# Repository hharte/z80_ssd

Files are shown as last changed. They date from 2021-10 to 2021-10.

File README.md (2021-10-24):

# z80_ssd: Z-80 Solid-State Drive

## Introduction

This project implements a solid-state disk controller for the Z80.  The board plugs into the Z80 CPU socket and the Z80 CPU plugs into the board.  A [Microchip PIC18F47Q43](https://www.microchip.com/en-us/product/PIC18F47Q43) microcontroller implements the controller and SD Memory card interface using SPI.

While the z80_ssd could implement almost any hard disk controller that uses I/O ports for data transfer, the particular controller implemented mimics the IBC/Integrated Business Computers MCC Hard Disk Controller.

The original controller supports four ST-506 drives.  Drive 0 is the boot drive, and Drive 3 is a 5- or 10MB removable cartridge drive.  The other two drives were unused in the standard [IBC MultiStar](https://github.com/hharte/integrated-business-computers/tree/master/MultiStar) computer.

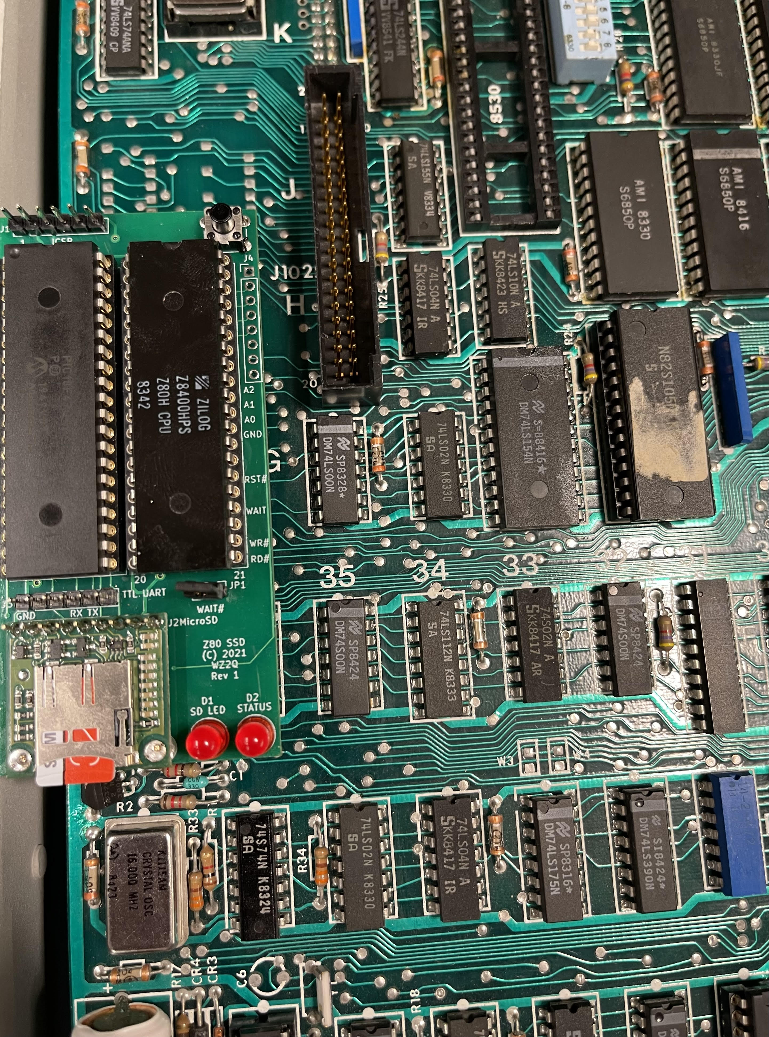
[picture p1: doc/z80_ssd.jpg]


## Architecture

### I/O Access Handling

The z80_ssd piggybacks on the Z80 CPU socket to gain access to all of the Z80 CPU’s signals.  The PIC18F47Q43 was chosen because it has a relatively large amount of RAM (8K) and FLASH (128K.)  To minimize the number of components required, and to facilitate maximum flexibility, the MCU’s Configurable Logic Cells (CLCs) are used:

CLC1 - Decodes CPU_A[7:4] to allow the z80_ssd to respond to a block of 16 I/O addresses.  The current design uses one 4-input AND gate to decode address 40h-4Fh, like the original disk controller.  There are three spare 4-input AND gates in CLC1, so the design could be expanded to decode up to four blocks of 16 I/O ports if desired.

This schematic diagram illustrates three address ranges decoded by the z80_ssd: 40h-4Fh, 0C0h-0CFh, 0D0h-0DFh.

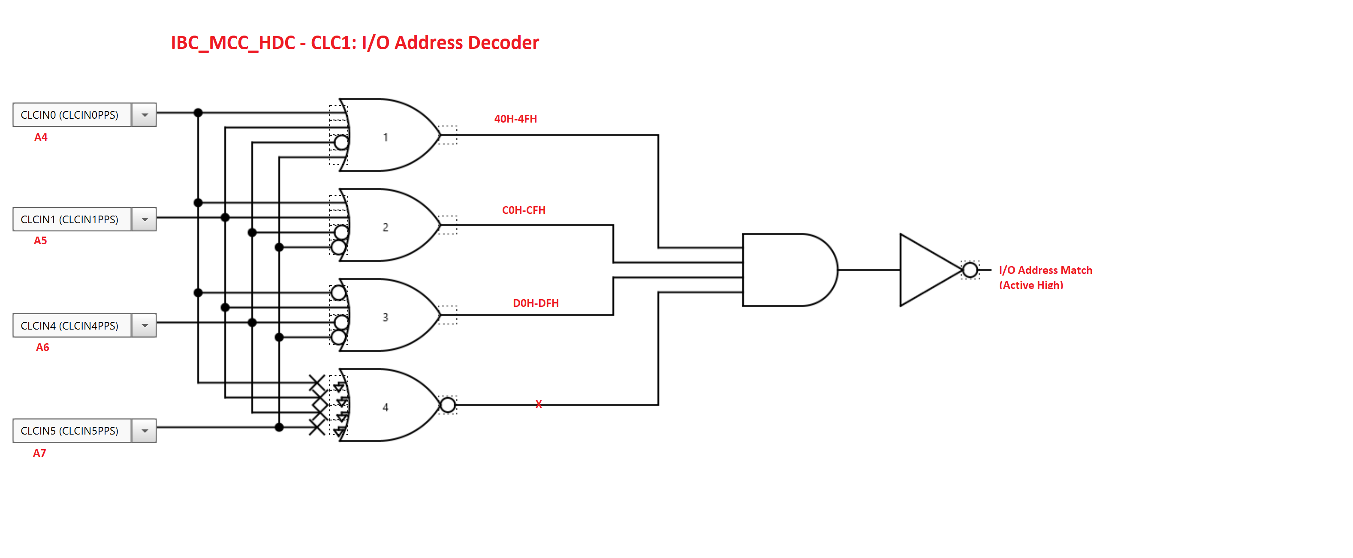
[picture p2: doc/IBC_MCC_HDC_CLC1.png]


CLC2 - Uses the output of CLC1 along with CPU_M1# and CPU_IORQ# to set a flip-flop when the requested I/O access is performed by the CPU.  The output of this flip-flop pulls down the CPU_WAIT# pin via an open-collector output from the MCU.  CLC2 generates an interrupt to the MCU, and MCU then processes the I/O read or write.  After the MCU finishes processing the I/O access, it de-asserts WAIT# by resetting the flip-flop in CLC2.

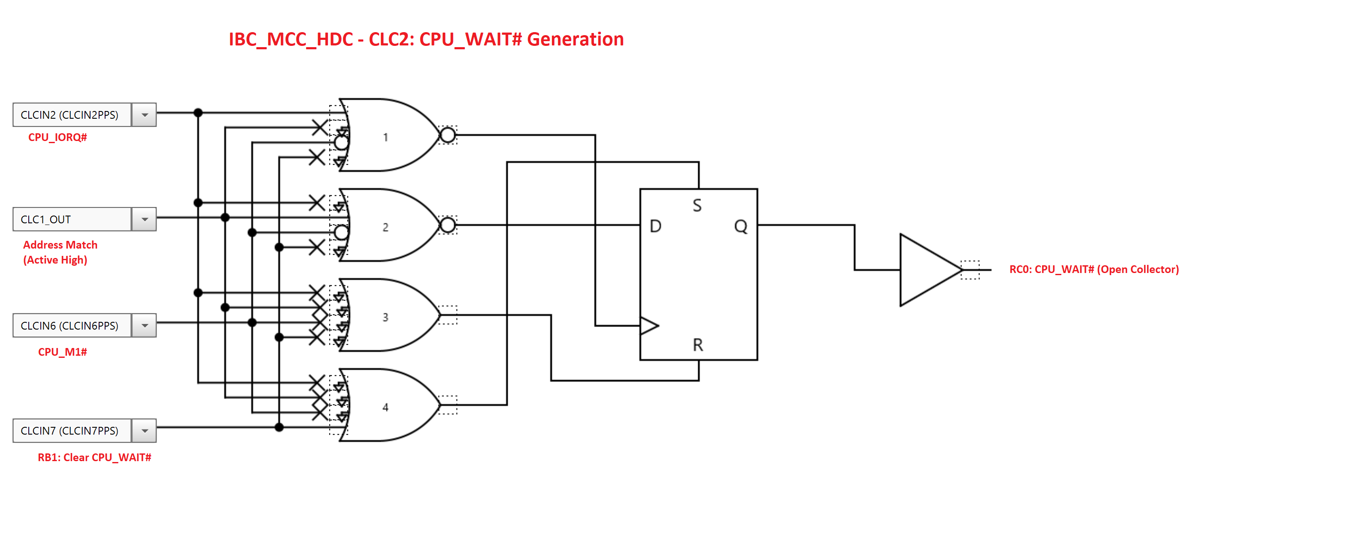
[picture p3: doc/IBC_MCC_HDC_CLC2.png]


CLC3 - Although not strictly required, the z80_ssd employs a 74ABTH245 bus transceiver for the CPU data bus to ensure proper timing.  The MCU’s CLC3 drives the bus transceiver’s output enable.

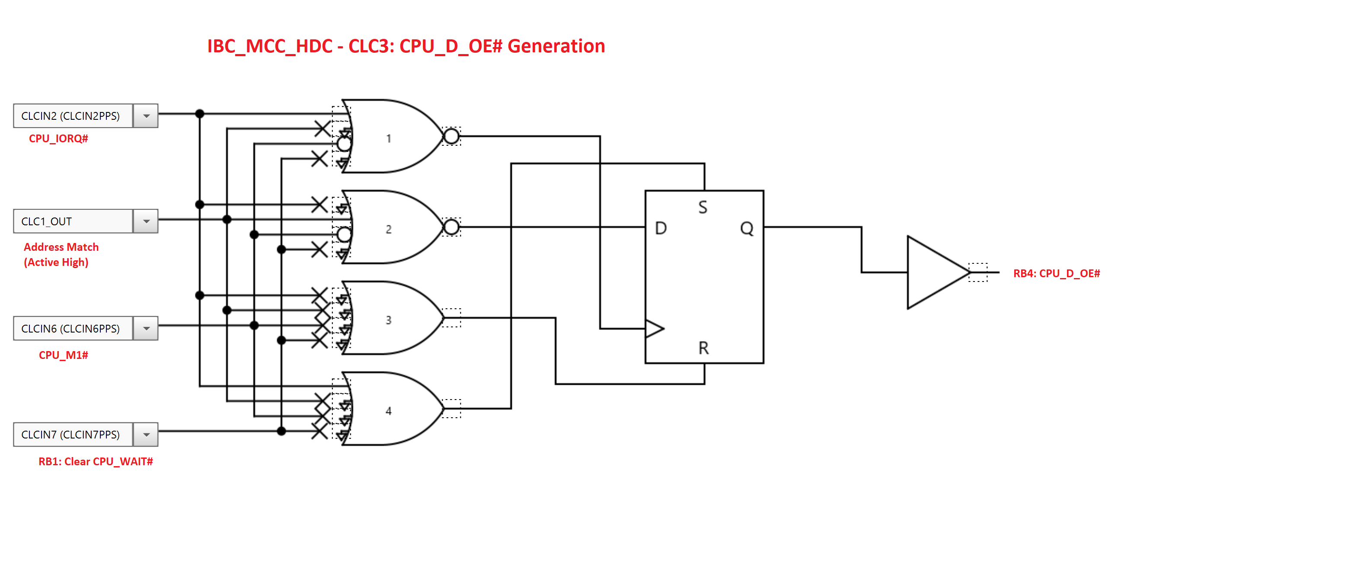
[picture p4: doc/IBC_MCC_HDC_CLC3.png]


Due to the piggyback nature of the z80_ssd, it is fabricated on a 0.4mm thick PCB, and uses a machined Mill-Max long-pin DIP socket.  To raise the z80_ssd above other components on the computer’s motherboard, the long-pin DIP is plugged into a stamped 40-pin DIP socket which is then inserted into the original Z80 CPU socket.

### SD Memory Card

The SD memory card is connected to the MCU’s SPI interface.  It uses the [FatFs library](http://elm-chan.org/fsw/ff/00index_e.html) and Microchip’s SD-SPI library.  The activity LED on the z80_ssd is driven by the SD memory card’s CS# pin.

The SPI clock runs at 8MHz, and is in polled mode.  It may be possible to increase the throughput by using interrupt-driven DMA mode, but I have not tried that.

Running OASIS 5.6, a 16MB disk partition can be verified (read) in 3 minutes, 35 seconds.  While the I/O interface is much slower than the hardware-driven FIFO of the original disk controller design, the overall performance feels about the same: solid-state disks do not have seek or rotational latency overhead, which makes these aspects of the disk faster than the original.

```
>HDPERF

>SHOW TIME
05:33:00 Friday, October 22, 1993

>VERIFY S

Cylinder: 132 Head: 14

>SHOW TIME
05:36:33 Friday, October 22, 1993

D(8) Label: "REMOVBKU",
     Archived from disk "HOWARD1 " on 10/23/83 14:13,
     Capacity: 9,744K bytes (609-2-32),
     Available: 0K bytes (0%),
     Largest area: 0K bytes,
     1 file in use (out of 16).

S(3) Label: "HOWARD1 ",
     Archived to disk "REMOVBKU" on 10/23/83 14:13,
     Capacity: 15,960K bytes (133-15-32),
     Available: 14,884K bytes (93%),
     Largest area: 14,879K bytes,
     188 files in use (out of 1,944).
```

### Debugging Facilities

The z80_ssd includes a 5V TTL UART for console I/O as well as a standard Microchip ICSP port on a 1x6 0.1” header.

Jumper JP1 can be removed to block CPU_WAIT# from being asserted.  This can be useful for debugging.  JP1 should be installed for normal operation.

## Other Uses

The z80_ssd hardware and MCU can be used to implement other types of I/O devices or different kinds of disk controllers.  One thing to be aware of is that **_no other hardware in the system should drive the bus when the z80_ssd registers are accessed_**.  For use in an S-100 bus system, additional logic would be needed to prevent the bus drivers on the S-100 board from driving against the z80_ssd.  In the IBC MultiStar machine where I use the z80_ssd, I had to disable the on-board ST-506 controller.  This was accomplished by removing the PAL that does the address decoding for the disk controller, tying one of the inputs inactive, and then placing the PAL back into the system.

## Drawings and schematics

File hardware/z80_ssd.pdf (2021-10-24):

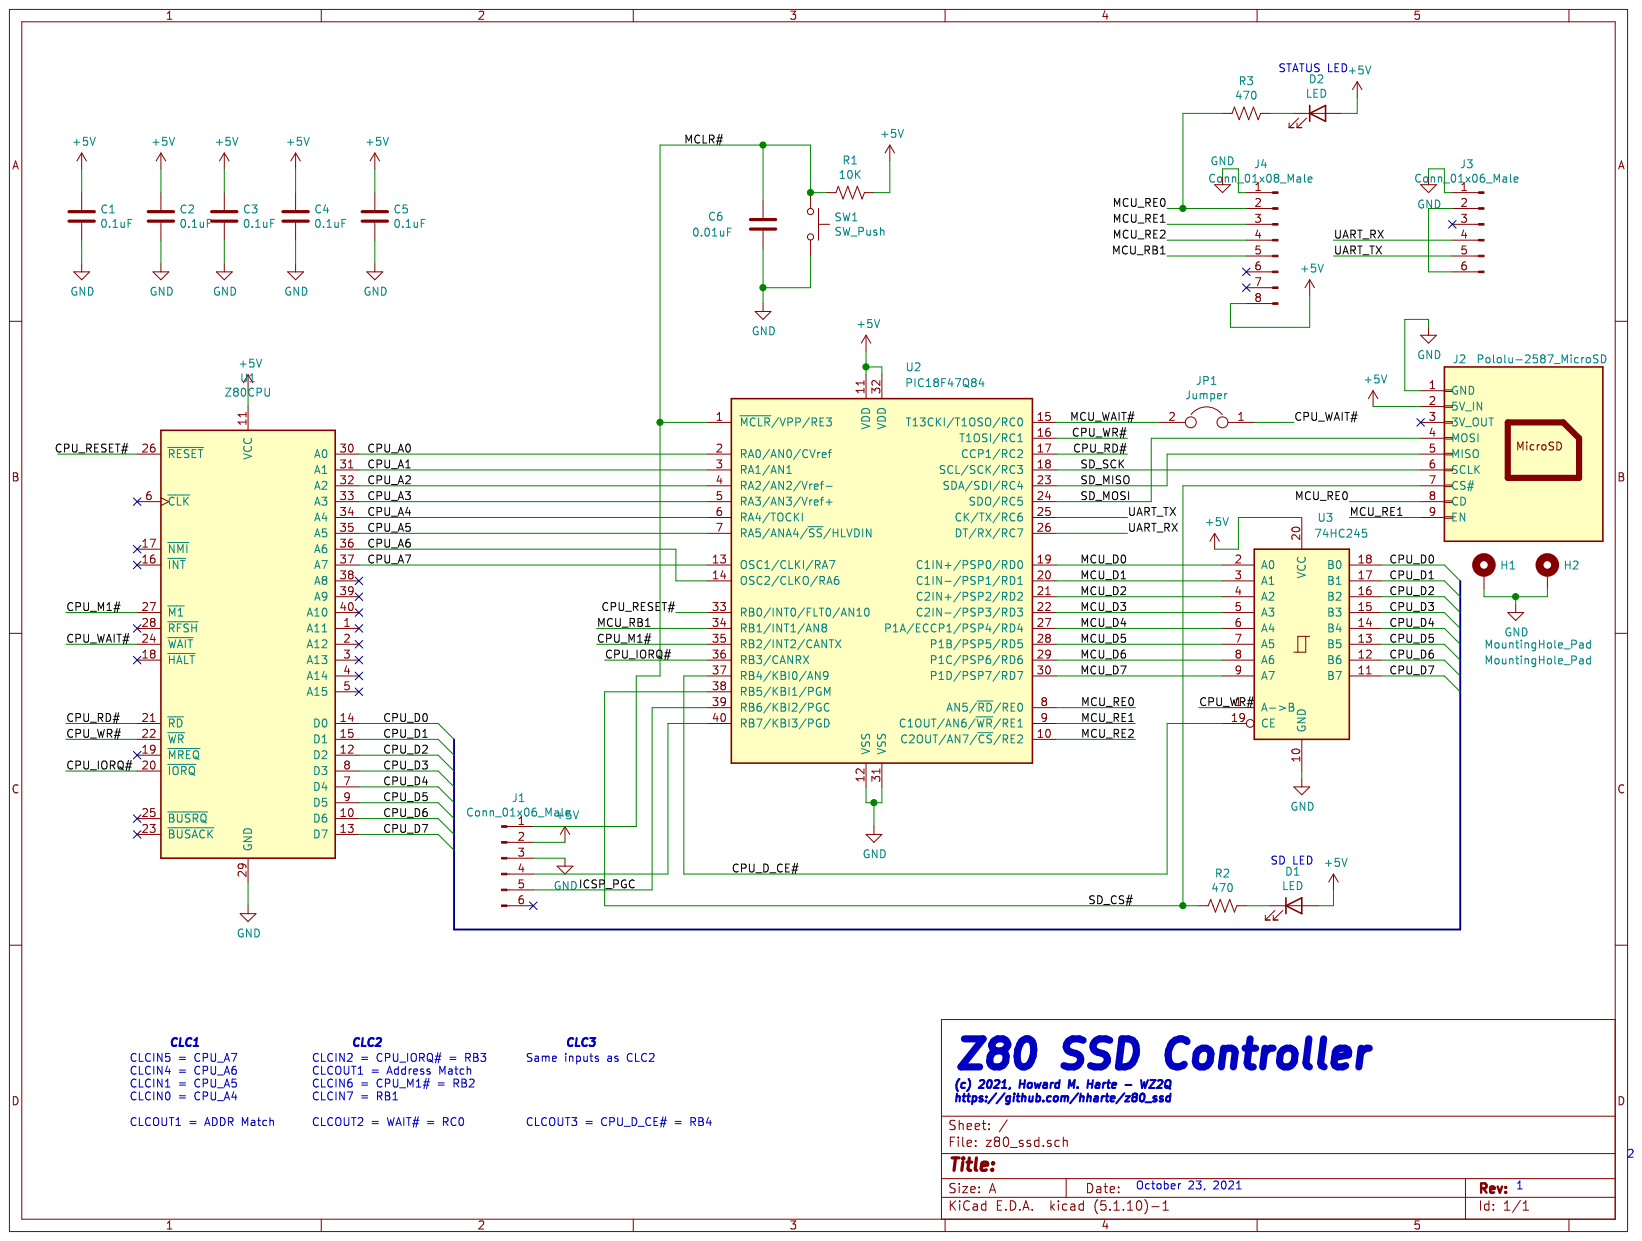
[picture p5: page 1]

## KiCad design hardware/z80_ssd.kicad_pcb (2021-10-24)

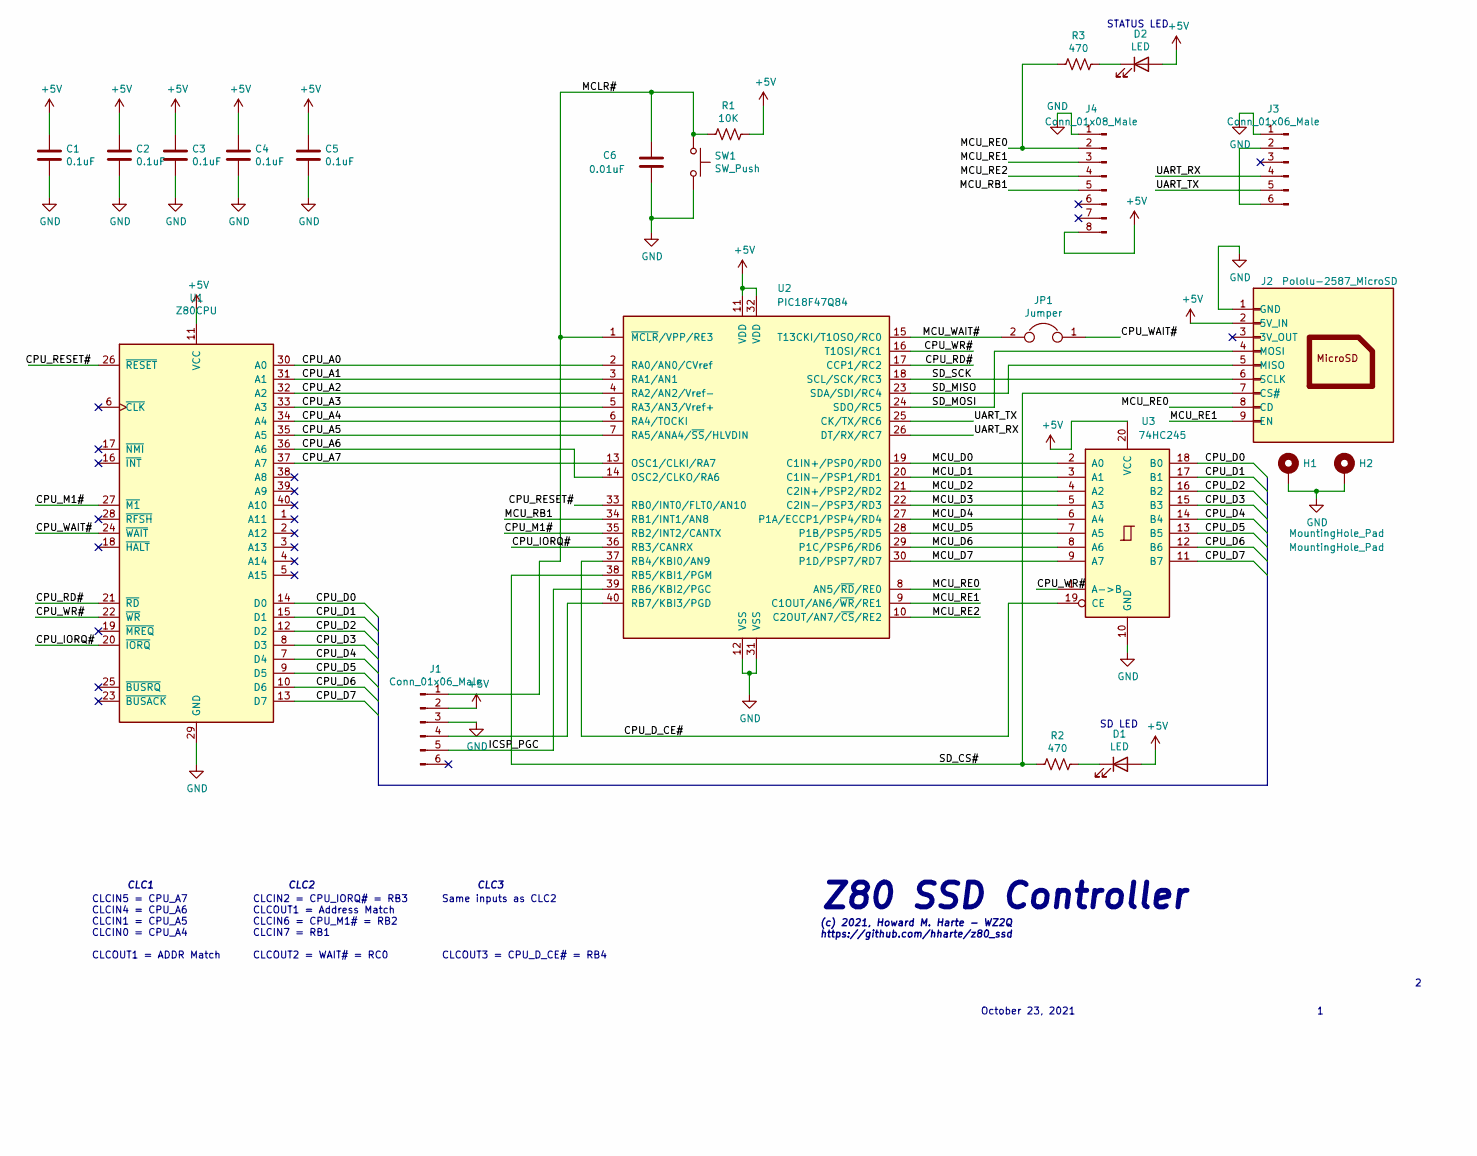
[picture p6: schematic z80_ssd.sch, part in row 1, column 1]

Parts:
C1, C2, C3, C4, C5: 0.1uF; C_0805_2012Metric
C6: 0.01uF; C_0805_2012Metric
D1, D2: LED; LED_D5.0mm
H1, H2: MountingHole_Pad; MountingHole_2.2mm_M2_Pad
J1, J3: Conn_01x06_Male; PinHeader_1x06_P2.54mm_Vertical
J2: Pololu-2587_MicroSD; PinHeader_1x09_P2.54mm_Vertical
J4: Conn_01x08_Male; PinHeader_1x08_P2.54mm_Vertical
JP1: Jumper; PinHeader_1x02_P2.54mm_Vertical
R1: 10K; R_0805_2012Metric
R2, R3: 470; R_0805_2012Metric
SW1: SW_Push; SW_PUSH_6mm
U1: Z80CPU; DIP-40_W15.24mm_Socket
U2: PIC18F47Q84; DIP-40_W15.24mm_Socket
U3: 74HC245; SSOP-20_4.4x6.5mm_P0.65mm

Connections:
+5V: C1.1, C2.1, C3.1, C4.1, C5.1, D1.2 (A), D2.2 (A), J1.2, J2.2 (5V_IN), J4.8, R1.1, U1.11 (VCC), U2.11 (VDD), U2.32 (VDD), U3.20 (VCC)
/CPU_A0: U1.30 (A0), U2.2 (RA0/AN0/CVref)
/CPU_A1: U1.31 (A1), U2.3 (RA1/AN1)
/CPU_A2: U1.32 (A2), U2.4 (RA2/AN2/Vref-)
/CPU_A3: U1.33 (A3), U2.5 (RA3/AN3/Vref+)
/CPU_A4: U1.34 (A4), U2.6 (RA4/TOCKI)
/CPU_A5: U1.35 (A5), U2.7 (RA5/ANA4/~SS~/HLVDIN)
/CPU_A6: U1.36 (A6), U2.14 (OSC2/CLKO/RA6)
/CPU_A7: U1.37 (A7), U2.13 (OSC1/CLKI/RA7)
/CPU_D0: U1.14 (D0), U3.18 (B0)
/CPU_D1: U1.15 (D1), U3.17 (B1)
/CPU_D2: U1.12 (D2), U3.16 (B2)
/CPU_D3: U1.8 (D3), U3.15 (B3)
/CPU_D4: U1.7 (D4), U3.14 (B4)
/CPU_D5: U1.9 (D5), U3.13 (B5)
/CPU_D6: U1.10 (D6), U3.12 (B6)
/CPU_D7: U1.13 (D7), U3.11 (B7)
/CPU_D_CE#: U2.37 (RB4/KBI0/AN9), U3.19 (CE)
/CPU_IORQ#: U1.20 (~IORQ~), U2.36 (RB3/CANRX)
/CPU_M1#: U1.27 (~M1~), U2.35 (RB2/INT2/CANTX)
/CPU_RD#: U1.21 (~RD~), U2.17 (CCP1/RC2)
/CPU_RESET#: U1.26 (~RESET~), U2.33 (RB0/INT0/FLT0/AN10)
/CPU_WAIT#: JP1.1, U1.24 (~WAIT~)
/CPU_WR#: U1.22 (~WR~), U2.16 (T1OSI/RC1), U3.1 (A->B)
/ICSP_PGC: J1.5, U2.39 (RB6/KBI2/PGC)
/MCLR#: C6.1, J1.1, R1.2, SW1.1, U2.1 (~MCLR~/VPP/RE3)
/MCU_D0: U2.19 (C1IN+/PSP0/RD0), U3.2 (A0)
/MCU_D1: U2.20 (C1IN-/PSP1/RD1), U3.3 (A1)
/MCU_D2: U2.21 (C2IN+/PSP2/RD2), U3.4 (A2)
/MCU_D3: U2.22 (C2IN-/PSP3/RD3), U3.5 (A3)
/MCU_D4: U2.27 (P1A/ECCP1/PSP4/RD4), U3.6 (A4)
/MCU_D5: U2.28 (P1B/PSP5/RD5), U3.7 (A5)
/MCU_D6: U2.29 (P1C/PSP6/RD6), U3.8 (A6)
/MCU_D7: U2.30 (P1D/PSP7/RD7), U3.9 (A7)
/MCU_RB1: J4.5, U2.34 (RB1/INT1/AN8)
/MCU_RE0: J2.8 (CD), J4.2, R3.2, U2.8 (AN5/~RD~/RE0)
/MCU_RE1: J2.9 (EN), J4.3, U2.9 (C1OUT/AN6/~WR~/RE1)
/MCU_RE2: J4.4, U2.10 (C2OUT/AN7/~CS~/RE2)
/MCU_WAIT#: JP1.2, U2.15 (T13CKI/T1OSO/RC0)
/SD_CS#: J2.7 (CS#), R2.2, U2.38 (RB5/KBI1/PGM)
/SD_MISO: J2.5 (MISO), U2.23 (SDA/SDI/RC4)
/SD_MOSI: J2.4 (MOSI), U2.24 (SDO/RC5)
/SD_SCK: J2.6 (SCLK), U2.18 (SCL/SCK/RC3)
/UART_RX: J3.4, U2.26 (DT/RX/RC7)
/UART_TX: J3.5, U2.25 (CK/TX/RC6)
GND: C1.2, C2.2, C3.2, C4.2, C5.2, C6.2, H1.1, H2.1, J1.3, J2.1 (GND), J3.1, J4.1, SW1.2, U1.29 (GND), U2.12 (VSS), U2.31 (VSS), U3.10 (GND)
unnamed: D1.1 (K), R2.1
unnamed: D2.1 (K), R3.1
unnamed: J1.4, U2.40 (RB7/KBI3/PGD)
unnamed: J3.2, J3.6

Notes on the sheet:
1D Coin Controller
1D Coin Controller - Microcontroller
2020-06-27
(c) 2020, Howard M. Harte - WZ2Q https://github.com/hharte/1dcoinctrl
CLCIN5 = CPU_A7 CLCIN4 = CPU_A6 CLCIN1 = CPU_A5 CLCIN0 = CPU_A4 CLCOUT1 = ADDR Match
CLCIN2 = CPU_IORQ# = RB3 CLCOUT1 = Address Match CLCIN6 = CPU_M1# = RB2 CLCIN7 = RB1 CLCOUT2 = WAIT# = RC0
Same inputs as CLC2 CLCOUT3 = CPU_D_CE# = RB4
Z80 SSD Controller
(c) 2021, Howard M. Harte - WZ2Q https://github.com/hharte/z80_ssd
October 23, 2021
CLC1
CLC2
CLC3
SD LED
STATUS LED

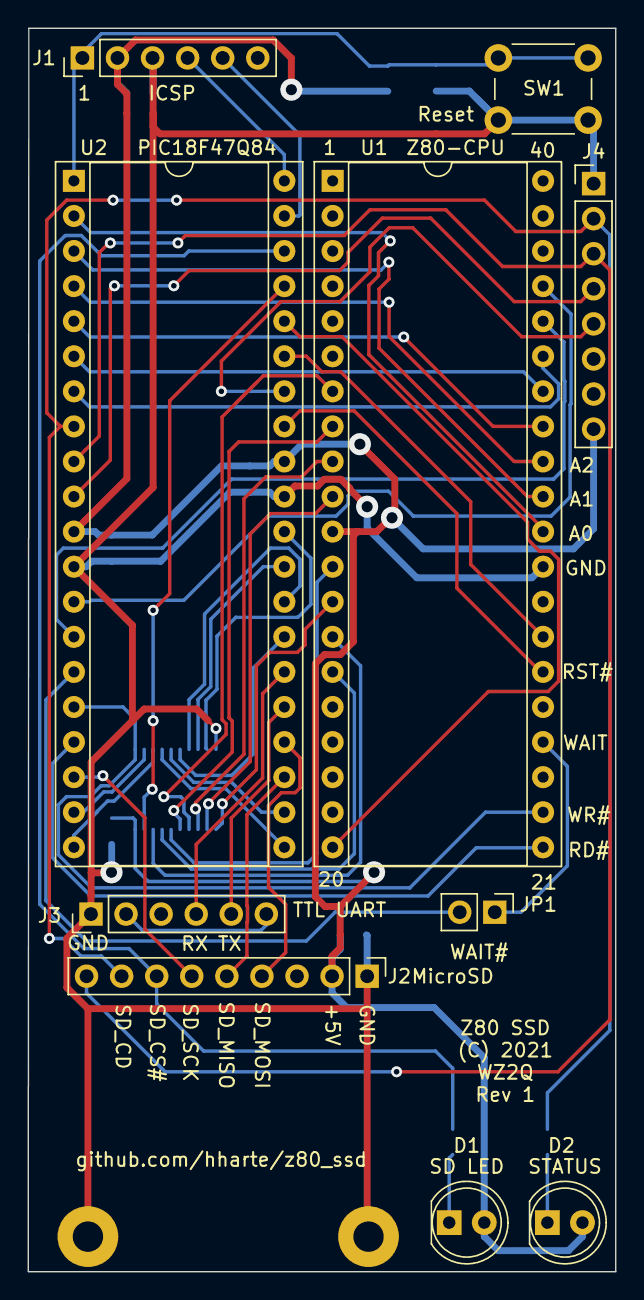
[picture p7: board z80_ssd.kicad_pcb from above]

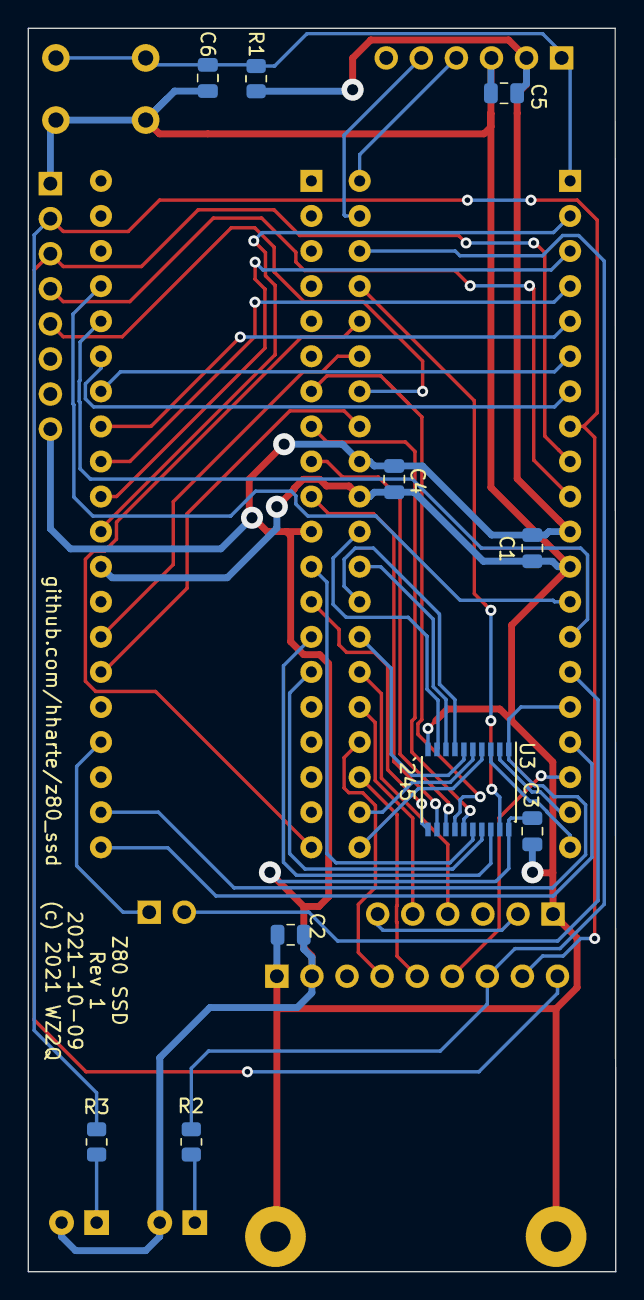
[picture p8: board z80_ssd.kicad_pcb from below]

Board: 2 copper layers, 42.5 x 90.0 mm, 22 parts (10 on the bottom side), 50 nets.

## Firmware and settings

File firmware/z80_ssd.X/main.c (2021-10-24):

/**
  Generated Main Source File

  Company:
    Microchip Technology Inc.

  File Name:
    main.c

  Summary:
    This is the main file generated using PIC10 / PIC12 / PIC16 / PIC18 MCUs

  Description:
    This header file provides implementations for driver APIs for all modules selected in the GUI.
    Generation Information :
        Product Revision  :  PIC10 / PIC12 / PIC16 / PIC18 MCUs - 1.81.7
        Device            :  PIC18F47Q43
        Driver Version    :  2.00
*/

/*
    (c) 2018 Microchip Technology Inc. and its subsidiaries. 
    
    Subject to your compliance with these terms, you may use Microchip software and any 
    derivatives exclusively with Microchip products. It is your responsibility to comply with third party 
    license terms applicable to your use of third party software (including open source software) that 
    may accompany Microchip software.
    
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
    IN NO EVENT WILL MICROCHIP BE LIABLE FOR ANY INDIRECT, SPECIAL, PUNITIVE, 
    INCIDENTAL OR CONSEQUENTIAL LOSS, DAMAGE, COST OR EXPENSE OF ANY KIND 
    WHATSOEVER RELATED TO THE SOFTWARE, HOWEVER CAUSED, EVEN IF MICROCHIP 
    HAS BEEN ADVISED OF THE POSSIBILITY OR THE DAMAGES ARE FORESEEABLE. TO 
    THE FULLEST EXTENT ALLOWED BY LAW, MICROCHIP'S TOTAL LIABILITY ON ALL 
    CLAIMS IN ANY WAY RELATED TO THIS SOFTWARE WILL NOT EXCEED THE AMOUNT 
    OF FEES, IF ANY, THAT YOU HAVE PAID DIRECTLY TO MICROCHIP FOR THIS 
    SOFTWARE.
*/

#include "mcc_generated_files/mcc.h"

extern void z80_ssd_main(void);

/*
                         Main application
 */
void main(void)
{
    
    // Initialize the device
    SYSTEM_Initialize();

    // If using interrupts in PIC18 High/Low Priority Mode you need to enable the Global High and Low Interrupts
    // If using interrupts in PIC Mid-Range Compatibility Mode you need to enable the Global Interrupts
    // Use the following macros to:

    // Enable high priority global interrupts
    INTERRUPT_GlobalInterruptHighEnable();

    // Enable low priority global interrupts.
    INTERRUPT_GlobalInterruptLowEnable();

    // Disable high priority global interrupts
    //INTERRUPT_GlobalInterruptHighDisable();

    // Disable low priority global interrupts.
    //INTERRUPT_GlobalInterruptLowDisable();

    z80_ssd_main();

    while (1)
    {
        // Add your application code
    }
}
/**
 End of File
*/

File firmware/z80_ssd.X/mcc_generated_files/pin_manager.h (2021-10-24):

/**
  @Generated Pin Manager Header File

  @Company:
    Microchip Technology Inc.

  @File Name:
    pin_manager.h

  @Summary:
    This is the Pin Manager file generated using PIC10 / PIC12 / PIC16 / PIC18 MCUs

  @Description
    This header file provides APIs for driver for .
    Generation Information :
        Product Revision  :  PIC10 / PIC12 / PIC16 / PIC18 MCUs - 1.81.7
        Device            :  PIC18F47Q43
        Driver Version    :  2.11
    The generated drivers are tested against the following:
        Compiler          :  XC8 2.31 and above
        MPLAB 	          :  MPLAB X 5.45	
*/

/*
    (c) 2018 Microchip Technology Inc. and its subsidiaries. 
    
    Subject to your compliance with these terms, you may use Microchip software and any 
    derivatives exclusively with Microchip products. It is your responsibility to comply with third party 
    license terms applicable to your use of third party software (including open source software) that 
    may accompany Microchip software.
    
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
    IN NO EVENT WILL MICROCHIP BE LIABLE FOR ANY INDIRECT, SPECIAL, PUNITIVE, 
    INCIDENTAL OR CONSEQUENTIAL LOSS, DAMAGE, COST OR EXPENSE OF ANY KIND 
    WHATSOEVER RELATED TO THE SOFTWARE, HOWEVER CAUSED, EVEN IF MICROCHIP 
    HAS BEEN ADVISED OF THE POSSIBILITY OR THE DAMAGES ARE FORESEEABLE. TO 
    THE FULLEST EXTENT ALLOWED BY LAW, MICROCHIP'S TOTAL LIABILITY ON ALL 
    CLAIMS IN ANY WAY RELATED TO THIS SOFTWARE WILL NOT EXCEED THE AMOUNT 
    OF FEES, IF ANY, THAT YOU HAVE PAID DIRECTLY TO MICROCHIP FOR THIS 
    SOFTWARE.
*/

#ifndef PIN_MANAGER_H
#define PIN_MANAGER_H

/**
  Section: Included Files
*/

#include <xc.h>

#define INPUT   1
#define OUTPUT  0

#define HIGH    1
#define LOW     0

#define ANALOG      1
#define DIGITAL     0

#define PULL_UP_ENABLED      1
#define PULL_UP_DISABLED     0

// get/set CPU_A0 aliases
#define CPU_A0_TRIS                 TRISAbits.TRISA0
#define CPU_A0_LAT                  LATAbits.LATA0
#define CPU_A0_PORT                 PORTAbits.RA0
#define CPU_A0_WPU                  WPUAbits.WPUA0
#define CPU_A0_OD                   ODCONAbits.ODCA0
#define CPU_A0_ANS                  ANSELAbits.ANSELA0
#define CPU_A0_SetHigh()            do { LATAbits.LATA0 = 1; } while(0)
#define CPU_A0_SetLow()             do { LATAbits.LATA0 = 0; } while(0)
#define CPU_A0_Toggle()             do { LATAbits.LATA0 = ~LATAbits.LATA0; } while(0)
#define CPU_A0_GetValue()           PORTAbits.RA0
#define CPU_A0_SetDigitalInput()    do { TRISAbits.TRISA0 = 1; } while(0)
#define CPU_A0_SetDigitalOutput()   do { TRISAbits.TRISA0 = 0; } while(0)
#define CPU_A0_SetPullup()          do { WPUAbits.WPUA0 = 1; } while(0)
#define CPU_A0_ResetPullup()        do { WPUAbits.WPUA0 = 0; } while(0)
#define CPU_A0_SetPushPull()        do { ODCONAbits.ODCA0 = 0; } while(0)
#define CPU_A0_SetOpenDrain()       do { ODCONAbits.ODCA0 = 1; } while(0)
#define CPU_A0_SetAnalogMode()      do { ANSELAbits.ANSELA0 = 1; } while(0)
#define CPU_A0_SetDigitalMode()     do { ANSELAbits.ANSELA0 = 0; } while(0)

// get/set CPU_A1 aliases
#define CPU_A1_TRIS                 TRISAbits.TRISA1
#define CPU_A1_LAT                  LATAbits.LATA1
#define CPU_A1_PORT                 PORTAbits.RA1
#define CPU_A1_WPU                  WPUAbits.WPUA1
#define CPU_A1_OD                   ODCONAbits.ODCA1
#define CPU_A1_ANS                  ANSELAbits.ANSELA1
#define CPU_A1_SetHigh()            do { LATAbits.LATA1 = 1; } while(0)
#define CPU_A1_SetLow()             do { LATAbits.LATA1 = 0; } while(0)
#define CPU_A1_Toggle()             do { LATAbits.LATA1 = ~LATAbits.LATA1; } while(0)
#define CPU_A1_GetValue()           PORTAbits.RA1
#define CPU_A1_SetDigitalInput()    do { TRISAbits.TRISA1 = 1; } while(0)
#define CPU_A1_SetDigitalOutput()   do { TRISAbits.TRISA1 = 0; } while(0)
#define CPU_A1_SetPullup()          do { WPUAbits.WPUA1 = 1; } while(0)
#define CPU_A1_ResetPullup()        do { WPUAbits.WPUA1 = 0; } while(0)
#define CPU_A1_SetPushPull()        do { ODCONAbits.ODCA1 = 0; } while(0)
#define CPU_A1_SetOpenDrain()       do { ODCONAbits.ODCA1 = 1; } while(0)
#define CPU_A1_SetAnalogMode()      do { ANSELAbits.ANSELA1 = 1; } while(0)
#define CPU_A1_SetDigitalMode()     do { ANSELAbits.ANSELA1 = 0; } while(0)

// get/set CPU_A2 aliases
#define CPU_A2_TRIS                 TRISAbits.TRISA2
#define CPU_A2_LAT                  LATAbits.LATA2
#define CPU_A2_PORT                 PORTAbits.RA2
#define CPU_A2_WPU                  WPUAbits.WPUA2
#define CPU_A2_OD                   ODCONAbits.ODCA2
#define CPU_A2_ANS                  ANSELAbits.ANSELA2
#define CPU_A2_SetHigh()            do { LATAbits.LATA2 = 1; } while(0)
#define CPU_A2_SetLow()             do { LATAbits.LATA2 = 0; } while(0)
#define CPU_A2_Toggle()             do { LATAbits.LATA2 = ~LATAbits.LATA2; } while(0)
#define CPU_A2_GetValue()           PORTAbits.RA2
#define CPU_A2_SetDigitalInput()    do { TRISAbits.TRISA2 = 1; } while(0)
#define CPU_A2_SetDigitalOutput()   do { TRISAbits.TRISA2 = 0; } while(0)
#define CPU_A2_SetPullup()          do { WPUAbits.WPUA2 = 1; } while(0)
#define CPU_A2_ResetPullup()        do { WPUAbits.WPUA2 = 0; } while(0)
#define CPU_A2_SetPushPull()        do { ODCONAbits.ODCA2 = 0; } while(0)
#define CPU_A2_SetOpenDrain()       do { ODCONAbits.ODCA2 = 1; } while(0)
#define CPU_A2_SetAnalogMode()      do { ANSELAbits.ANSELA2 = 1; } while(0)
#define CPU_A2_SetDigitalMode()     do { ANSELAbits.ANSELA2 = 0; } while(0)

// get/set CPU_A3 aliases
#define CPU_A3_TRIS                 TRISAbits.TRISA3
#define CPU_A3_LAT                  LATAbits.LATA3
#define CPU_A3_PORT                 PORTAbits.RA3
#define CPU_A3_WPU                  WPUAbits.WPUA3
#define CPU_A3_OD                   ODCONAbits.ODCA3
#define CPU_A3_ANS                  ANSELAbits.ANSELA3
#define CPU_A3_SetHigh()            do { LATAbits.LATA3 = 1; } while(0)
#define CPU_A3_SetLow()             do { LATAbits.LATA3 = 0; } while(0)
#define CPU_A3_Toggle()             do { LATAbits.LATA3 = ~LATAbits.LATA3; } while(0)
#define CPU_A3_GetValue()           PORTAbits.RA3
#define CPU_A3_SetDigitalInput()    do { TRISAbits.TRISA3 = 1; } while(0)
#define CPU_A3_SetDigitalOutput()   do { TRISAbits.TRISA3 = 0; } while(0)
#define CPU_A3_SetPullup()          do { WPUAbits.WPUA3 = 1; } while(0)
#define CPU_A3_ResetPullup()        do { WPUAbits.WPUA3 = 0; } while(0)
#define CPU_A3_SetPushPull()        do { ODCONAbits.ODCA3 = 0; } while(0)
#define CPU_A3_SetOpenDrain()       do { ODCONAbits.ODCA3 = 1; } while(0)
#define CPU_A3_SetAnalogMode()      do { ANSELAbits.ANSELA3 = 1; } while(0)
#define CPU_A3_SetDigitalMode()     do { ANSELAbits.ANSELA3 = 0; } while(0)
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

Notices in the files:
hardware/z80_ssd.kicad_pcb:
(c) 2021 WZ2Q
